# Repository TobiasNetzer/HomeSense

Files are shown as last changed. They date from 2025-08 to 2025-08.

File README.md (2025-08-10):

# HomeSense - IoT Environmental Sensor 

ESP32-C3 based IoT Temperature, Humidity, Air Quality and Air Pressure Sensor with logging capabilities. 

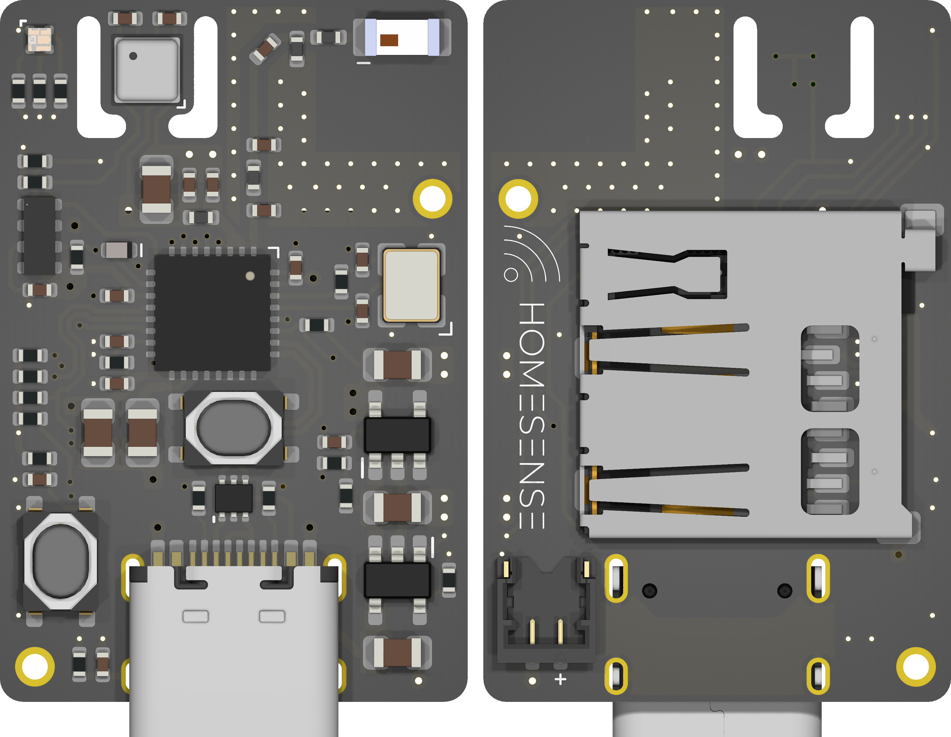
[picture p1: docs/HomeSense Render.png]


Initially, the idea was simply to monitor temperature and humidity wirelessly. Along the way, I chose the Bosch BME680 sensor, which also provides air pressure and air quality measurements.

Sensor data is primarily transmitted via MQTT. To ensure continued operation in the absence of Wi-Fi, the device also supports local data logging using a microSD card and includes a real-time clock (RTC) for accurate timestamps.

When considering the form factor I thought about using one of the pre-made ESP32-C3 modules. While that would have streamlined the design, I wanted the board to be as small as possible, so I went with a fully custom design.

The case fits a 250mAh battery and also embeds a small magnet in the back lid to allow it to be mounted on magnetic surfaces. I put in a small light pipe for the RGB-LED, a few ventilation holes/slots for the BME680 and a cutout for the microSD card.
Fully assembled it measures 15x25x35mm.

Take a look at the design documents for more info:
- [Schematic](docs/Schematic.pdf)
- [Assembly Drawing](docs/HomeSense%20Assembly%20Drawing.pdf)
- [BOM](https://htmlpreview.github.io/?https://github.com/TobiasNetzer/HomeSense/blob/main/docs/BOM.html)

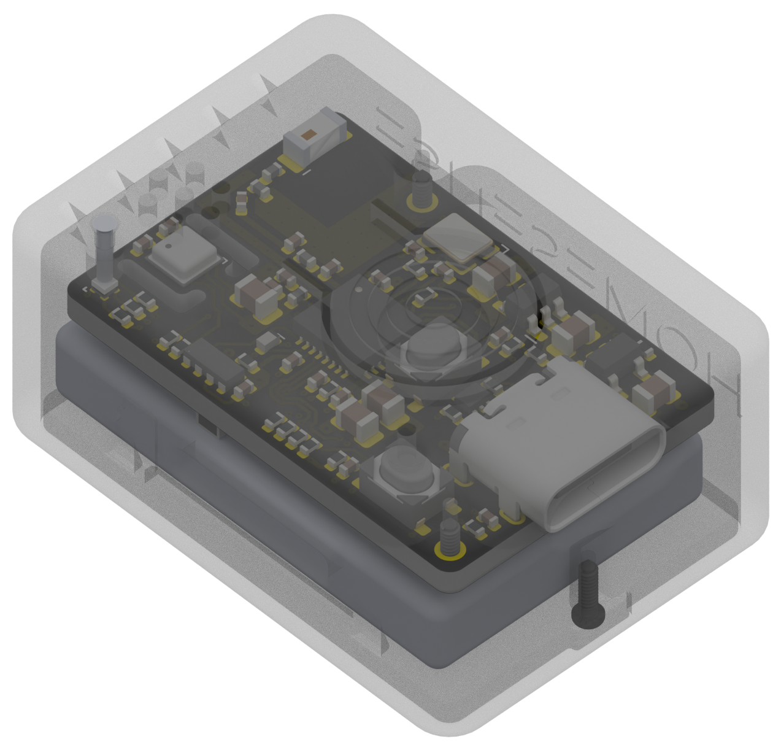
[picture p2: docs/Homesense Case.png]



# Data Acquisition 📊

Bosch supplies an API for the BME680 which can be used to get raw values from the sensor. This is good enough if you only want temperature and humidity for example. But the sensor is capable of quite a bit more, like providing indoor air quality levels. For this, the additional BSEC (Bosch Sensortec Environmental Cluster) software is needed. This library takes care of all the sensor fusion and provides ambient air temperature, ambient relative humidity, air pressure and indoor air quality (IAQ).

To configure the device, I made a super basic webpage, which is hosted by the ESP32. This allows setting up the Wi-Fi connection and MQTT. There is a lot to be added, but for initial testing this works fine.

Once everything is setup, a JSON string containing all the sensor data can be received every 15min by subscribing to the configured MQTT topic. 

Here is an example of the data:

```json
{
   "timestamp":"2023-07-15T13:03",
   "temperature":{
      "value":27.33,
      "unit":"Celsius"
   },
   "humidity":{
      "value":38.87,
      "unit":"percent"
   },
   "pressure":{
      "value":94787.31,
      "unit":"Pa"
   },
   "gas_resistance":{
      "value":211406.42,
      "unit":"Ohm"
   },
   "iaq":79.60,
   "iaq_accuracy":3,
   "static_iaq":79.18,
   "static_iaq_accuracy":3,
   "co2_equivalent":{
      "value":791.80,
      "unit":"ppm"
   },
   "breath_voc_equivalent":{
      "value":0.97,
      "unit":"ppm"
   },
   "gas_percentage":{
      "value":21.45,
      "unit":"percent"
   },
   "run_in_status":1,
   "stabilization_status":1,
   "battery_voltage":{
      "value":3868,
      "unit":"mV"
   }
}
```

# Issues

Unfortunately the thermal isolation cutouts around the BME680 aren't as effective as I had hoped. When the ESP32 is running continuously, like when the webserver for configuration is running, the temperature reading of the BME680 increases by around 3°C. Ofc the small footprint of the board also doesn't help, since there is very little distance between the ESP and the sensor.

Even though the cutouts seem to help a bit and the ground plane was removed below the sensor area, the bridge for the power and data lines provides a direct path for the heat. A complete U-shape would have probably been a much more effective design choice.

In order to avoid reporting false temperature and humidity data, the ESP has to be in sleep mode for some time to allow the board to cool down before taking another reading from the sensor.

This also applies while charging the battery. Currently the charge current is configured for 50mA, but this is still enough to increase the temperature readings by a small amount.

The workaround for now is to wait around 10min after the webserver is shut off, before taking the first reading and also disable any readings while charging. This isn't a huge problem, since data is only transmitted every 15min.

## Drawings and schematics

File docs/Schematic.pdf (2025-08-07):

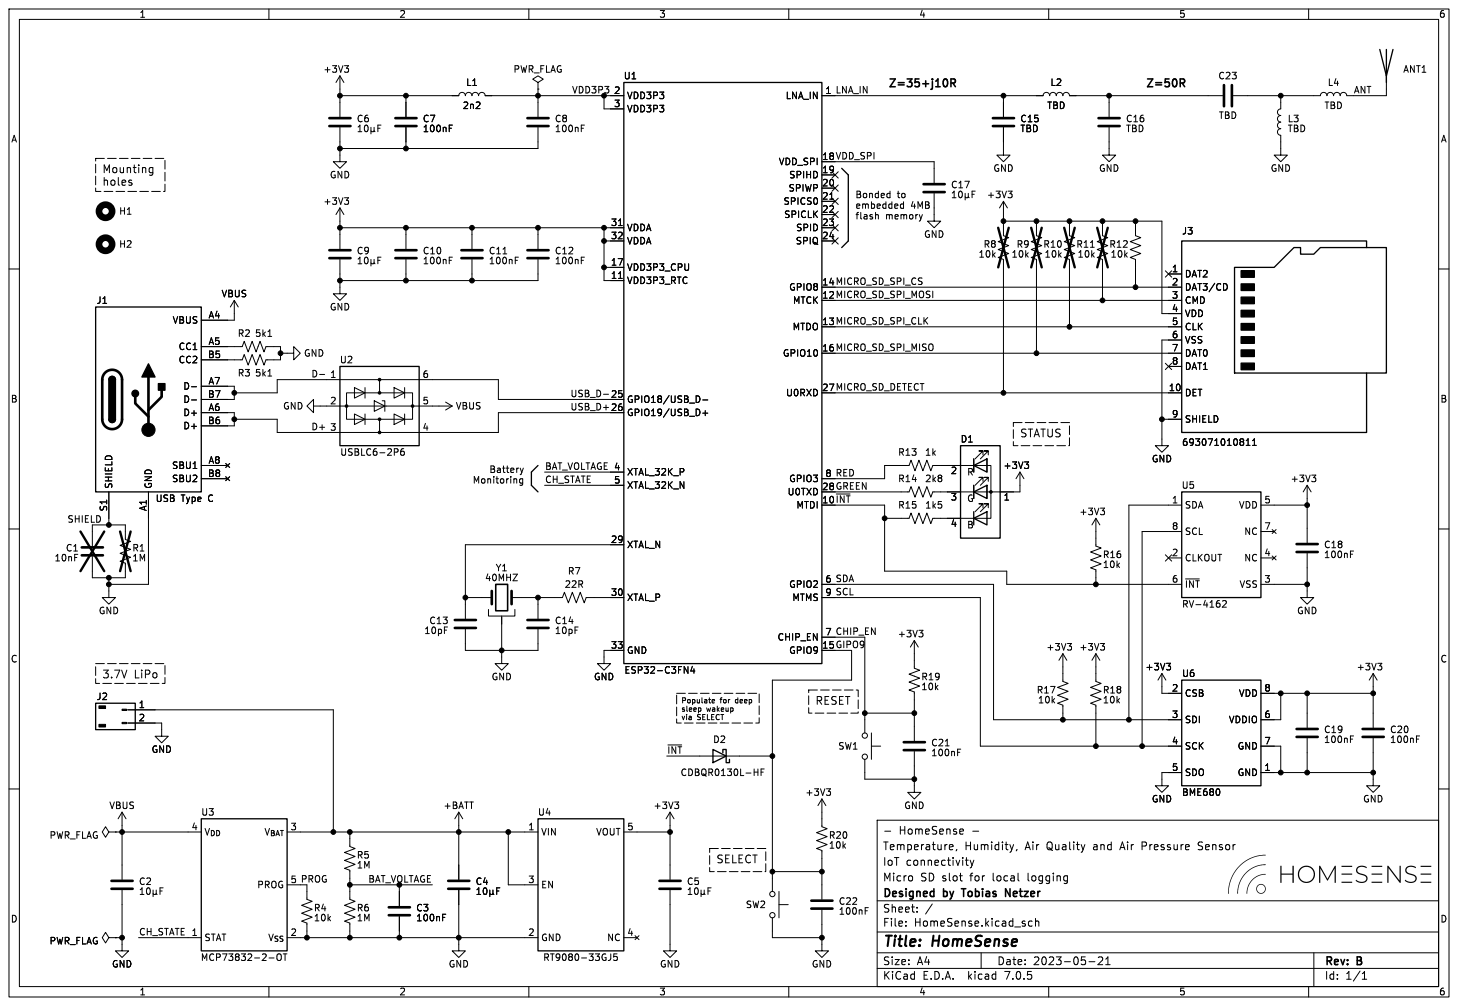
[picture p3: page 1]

693071010811 DAT2 1 DET 10 DAT3/CD 2 CMD 3 VDD 4 CLK 5 VSS 6 DAT0 7 DAT1 8 SHIELD 9 C15 TBD

GND
DAT2 1 DET 10 DAT3/CD 2 CMD 3 VDD 4 CLK 5 VSS 6 DAT0 7 DAT1 8 SHIELD 9

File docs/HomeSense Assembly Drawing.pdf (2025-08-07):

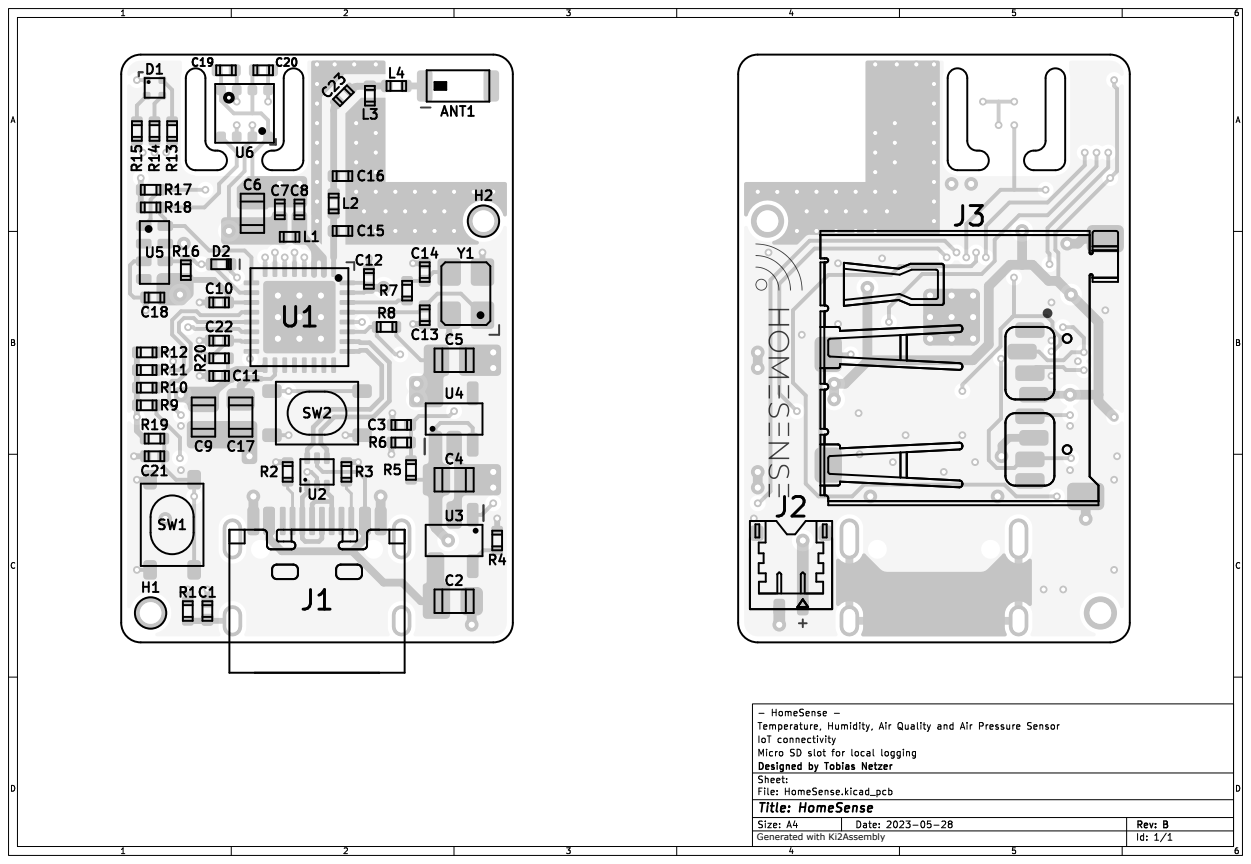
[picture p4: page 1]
Generated with Ki2Assembly

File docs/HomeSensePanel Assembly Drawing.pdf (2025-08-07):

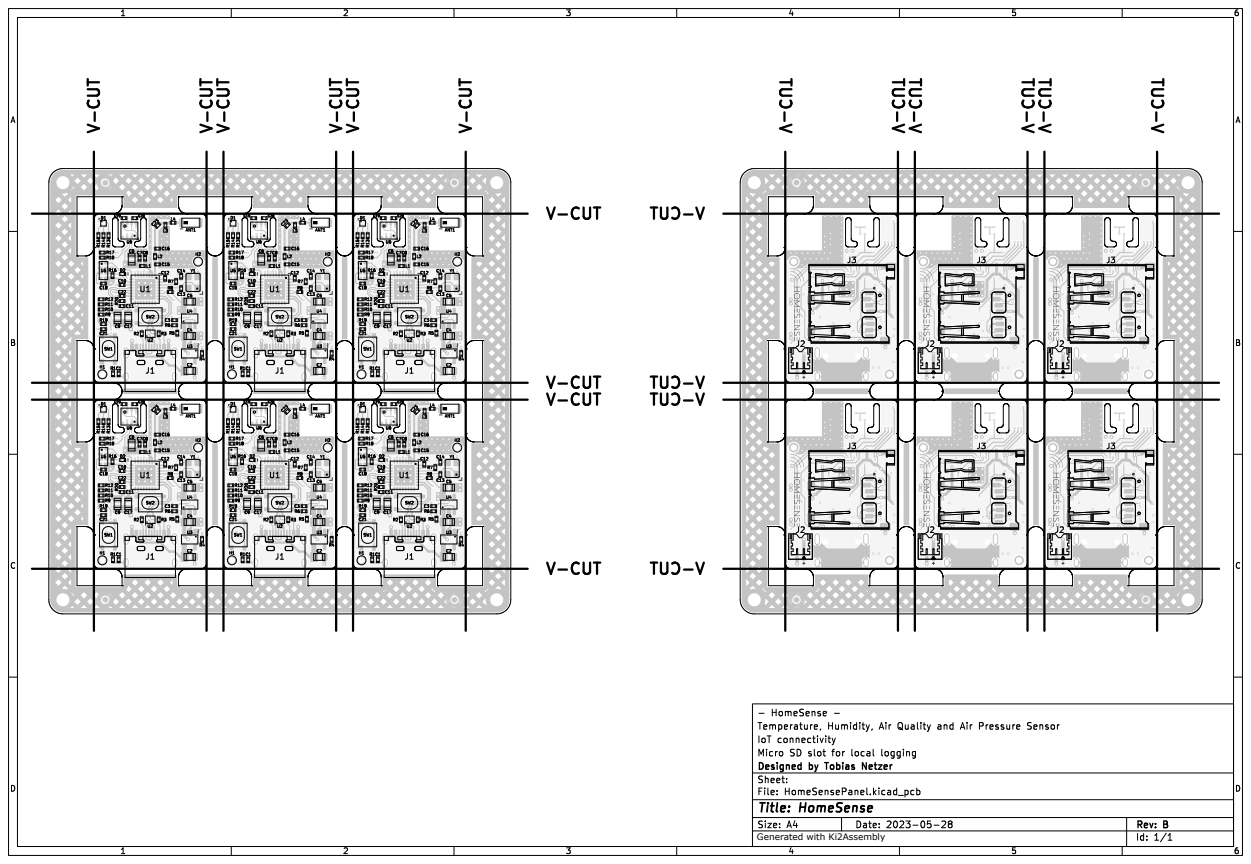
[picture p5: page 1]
Generated with Ki2Assembly

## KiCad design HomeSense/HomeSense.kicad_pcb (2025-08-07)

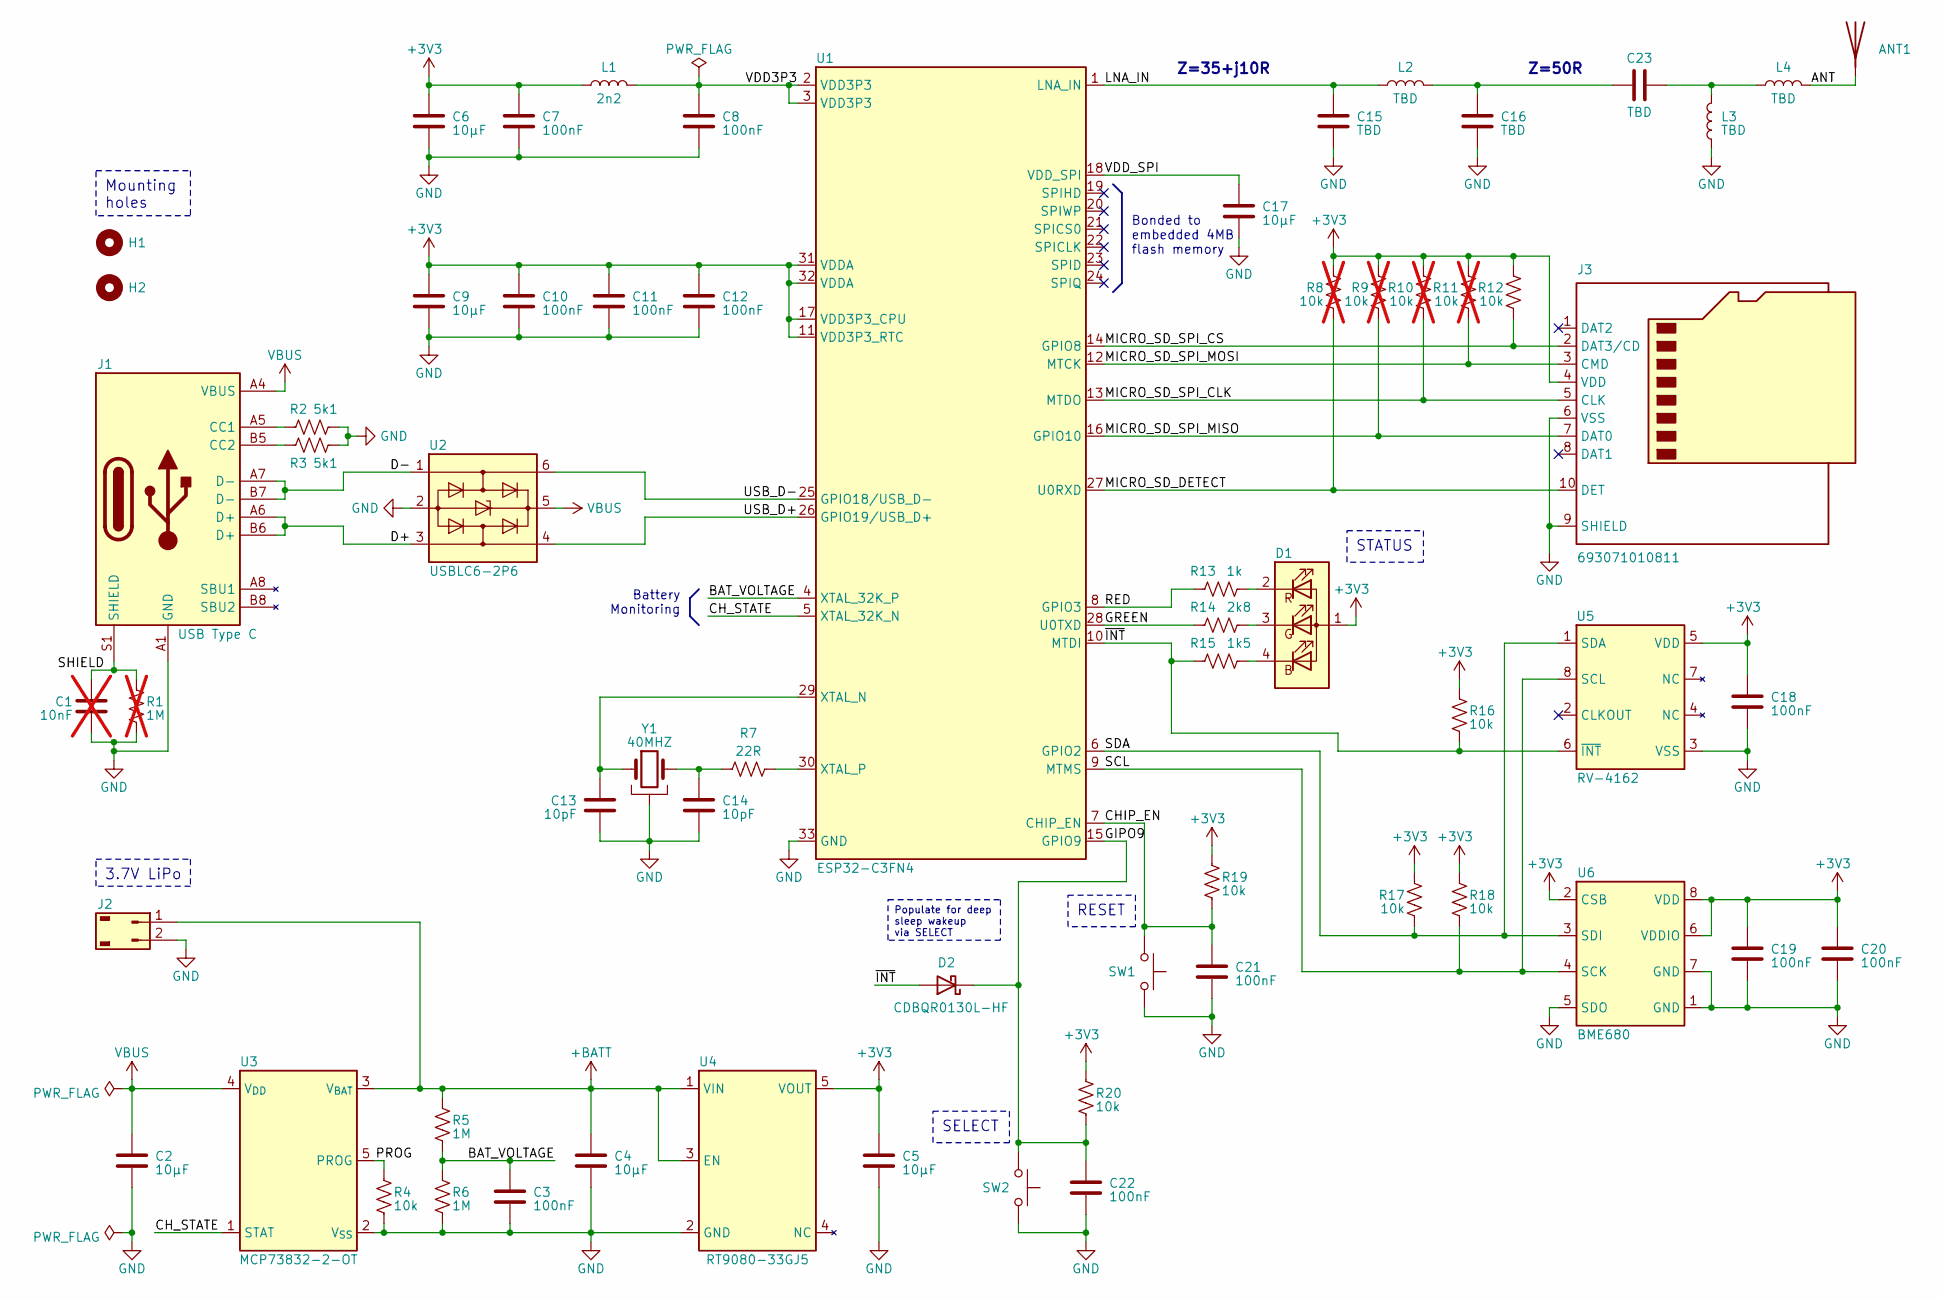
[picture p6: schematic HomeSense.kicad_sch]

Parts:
ANT1: 2450AT18B100E; Johanson_2450AT18x100; Manufacturer Part Number 2450AT18B100E
C1: 10nF; C_0402_(1005_Metric); Manufacturer Part Number C0402C103K5RAC7411; not fitted
C2, C4, C5, C6, C9, C17: 10µF; C_0805_(2012_Metric); Manufacturer Part Number C0805C106K3PAC7800
C3, C7, C8, C10, C11, C12, C18, C19, C20, C21, C22: 100nF; C_0402_(1005_Metric); Manufacturer Part Number C0402C104K3PAC7867
C13, C14: 10pF; C_0402_(1005_Metric); Manufacturer Part Number C0402C100J3GAC7867
C15, C16, C23: TBD; C_0402_(1005_Metric)
D1: Wuerth_150044M155260; LED_0404; Manufacturer Part Number 150044M155260
D2: CDBQR0130L-HF; D_0402_(1005_Metric); Manufacturer Part Number CDBQR0130L-HF
H1, H2: MountingHole; Mounting_Hole
J1: USB Type C; USB_C_Receptacle_HRO_TYPE-C-31-M-12; Manufacturer Part Number USB_C_Receptacle_HRO_TYPE-C-31-M-12
J2: 781710002; Molex_Pico-EZmate_78171-0002_1x02-1MP_P1.20mm_Vertical; Manufacturer Part Number 781710002
J3: 693071010811; Manufacturer Part Number 693071010811
L1: 2n2; L_0402_(1005_Metric); Manufacturer Part Number LQG15WH2N2S02D
L2, L3, L4: TBD; L_0402_(1005_Metric)
R1: 1M; R_0402_(1005_Metric); Manufacturer Part Number RC0402FR-071ML; not fitted
R2, R3: 5k1; R_0402_(1005_Metric); Manufacturer Part Number RC0402FR-075K1L
R4, R12, R16, R17, R18, R19, R20: 10k; R_0402_(1005_Metric); Manufacturer Part Number RC0402FR-0710KP
R5, R6: 1M; R_0402_(1005_Metric); Manufacturer Part Number RC0402FR-071ML
R7: 22R; R_0402_(1005_Metric); Manufacturer Part Number RC0402FR-0722RP
R8, R9, R10, R11: 10k; R_0402_(1005_Metric); Manufacturer Part Number RC0402FR-0710KP; not fitted
R13: 1k; R_0402_(1005_Metric); Manufacturer Part Number AC0402FR-131KL
R14: 2k8; R_0402_(1005_Metric); Manufacturer Part Number RC0402FR-072K8L
R15: 1k5; R_0402_(1005_Metric); Manufacturer Part Number RC0402FR-071K5L
SW1, SW2: SW_Push; Button_3.2mm_4.2mm; Manufacturer Part Number PTS810SJG250SMTRLFS
U1: ESP32-C3FN4; QFN32_5x5; Manufacturer Part Number ESP32-C3FN4
U2: USBLC6-2P6; SOT-666; Manufacturer Part Number USBLC6-2P6
U3: MCP73832-2-OT; SOT-23-5; Manufacturer Part Number MCP73832T-2DCI/OT
U4: RT9080-33GJ5; SOT-23-5; Manufacturer Part Number RT9080-33GJ5
U5: RV-4162; LCC8; Manufacturer Part Number RV-4162-C7-32.768KHZ-20PPM-TA-QC
U6: BME680; Bosch_LGA-8_3x3mm_P0.8mm; Manufacturer Part Number BME680
Y1: 40MHZ; Crystal_SMD_Abracon_ABM8G-4Pin_3.2x2.5mm; Manufacturer Part Number ABM8-40.000MHZ-10-1-U-T

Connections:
+3V3: C5.1, C6.1, C7.1, C9.1, C10.1, C11.1, C12.1, C18.1, C19.1, C20.1, D1.1 (A), J3.4 (VDD), L1.1, R8.1, R9.1, R10.1, R11.1, R12.1, R16.1, R17.1, R18.1, R19.1, R20.1, U1.11 (VDD3P3_RTC), U1.17 (VDD3P3_CPU), U1.31 (VDDA), U1.32 (VDDA), U4.5 (VOUT), U5.5 (VDD), U6.2 (CSB), U6.6 (VDDIO), U6.8 (VDD)
+BATT: C4.1, J2.1, R5.1, U3.3 (V_{BAT}), U4.1 (VIN), U4.3 (EN)
/ANT: ANT1.1 (A), L4.2
/BAT_VOLTAGE: C3.1, R5.2, R6.1, U1.4 (XTAL_32K_P)
/CHIP_EN: C21.1, R19.2, SW1.1, U1.7 (CHIP_EN)
/CH_STATE: U1.5 (XTAL_32K_N), U3.1 (STAT)
/D+: J1.A6 (D+), J1.B6 (D+), U2.3 (I/O2)
/D-: J1.A7 (D-), J1.B7 (D-), U2.1 (I/O1)
/GIPO9: C22.1, D2.1 (K), R20.2, SW2.1, U1.15 (GPIO9)
/GREEN: R14.1, U1.28 (U0TXD)
/LNA_IN: C15.1, L2.1, U1.1 (LNA_IN)
/MICRO_SD_DETECT: J3.10 (DET), R8.2, U1.27 (U0RXD)
/MICRO_SD_SPI_CLK: J3.5 (CLK), R10.2, U1.13 (MTDO)
/MICRO_SD_SPI_CS: J3.2 (DAT3/CD), R12.2, U1.14 (GPIO8)
/MICRO_SD_SPI_MISO: J3.7 (DAT0), R9.2, U1.16 (GPIO10)
/MICRO_SD_SPI_MOSI: J3.3 (CMD), R11.2, U1.12 (MTCK)
/PROG: R4.1, U3.5 (PROG)
/RED: R13.1, U1.8 (GPIO3)
/SCL: R18.2, U1.9 (MTMS), U5.8 (SCL), U6.4 (SCK)
/SDA: R17.2, U1.6 (GPIO2), U5.1 (SDA), U6.3 (SDI)
/SHIELD: C1.1, J1.S1 (SHIELD), R1.1
/USB_D+: U1.26 (GPIO19/USB_D+), U2.4 (I/O2)
/USB_D-: U1.25 (GPIO18/USB_D-), U2.6 (I/O1)
/VDD3P3: C8.1, L1.2, U1.2 (VDD3P3), U1.3 (VDD3P3)
/VDD_SPI: C17.1, U1.18 (VDD_SPI)
/~INT: D2.2 (A), R15.1, R16.2, U1.10 (MTDI), U5.6 (~INT)
GND: C1.2, C2.2, C3.2, C4.2, C5.2, C6.2, C7.2, C8.2, C9.2, C10.2, C11.2, C12.2, C13.2, C14.2, C15.2, C16.2, C17.2, C18.2, C19.2, C20.2, C21.2, C22.2, J1.A1 (GND), J1.A12 (GND), J1.B1 (GND), J1.B12 (GND), J2.2, J3.6 (VSS), J3.9 (SHIELD), L3.1, R1.2, R2.2, R3.2, R4.2, R6.2, SW1.2, SW2.2, U1.33 (GND), U2.2 (GND), U3.2 (V_{SS}), U4.2 (GND), U5.3 (VSS), U6.1 (GND), U6.5 (SDO), U6.7 (GND), Y1.2, Y1.4
unnamed: C14.1, R7.1, Y1.3
unnamed: C16.1, C23.1, L2.2
unnamed: C23.2, L3.2, L4.1
unnamed: D1.4 (BK), R15.2
unnamed: D1.3 (GK), R14.2
unnamed: D1.2 (RK), R13.2
unnamed: J1.A5 (CC1), R2.1
unnamed: J1.B5 (CC2), R3.1
unnamed: C13.1, U1.29 (XTAL_N), Y1.1
unnamed: R7.2, U1.30 (XTAL_P)
VBUS: C2.1, J1.A4 (VBUS), J1.A9 (VBUS), J1.B4 (VBUS), J1.B9 (VBUS), U2.5 (VBUS), U3.4 (V_{DD})

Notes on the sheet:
Z=35+j10R
Z=50R
Battery Monitoring
Bonded to embedded 4MB flash memory
STATUS
SELECT
Mounting holes
RESET
Populate for deep sleep wakeup via SELECT
3.7V LiPo

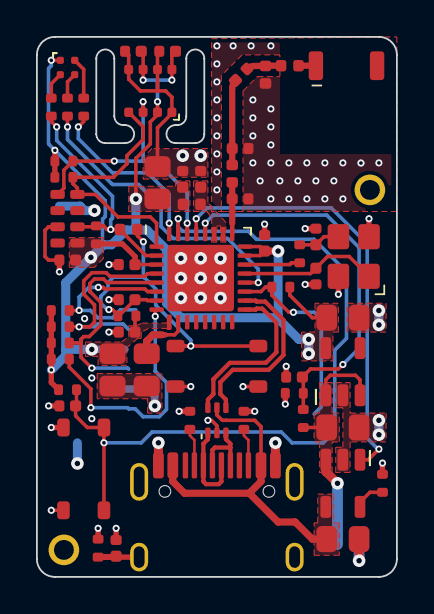
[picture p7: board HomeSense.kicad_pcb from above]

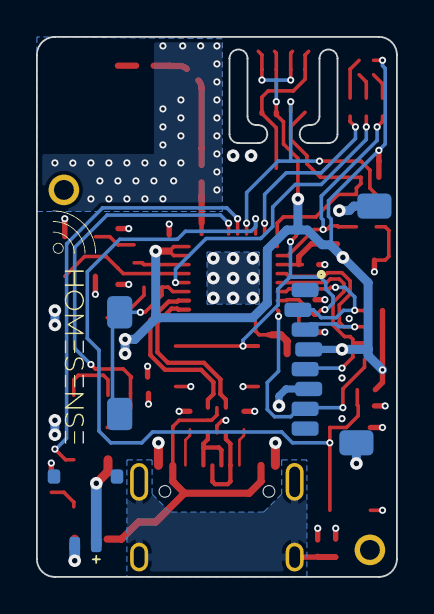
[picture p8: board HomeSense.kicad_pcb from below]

Board: 4 copper layers, 20.0 x 30.0 mm, 64 parts (2 on the bottom side), 38 nets.

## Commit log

2025-08-09 add case render
2025-08-10 add BOM
